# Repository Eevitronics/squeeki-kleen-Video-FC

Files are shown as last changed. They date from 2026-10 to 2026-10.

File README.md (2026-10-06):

# squeeki-kleen-Video-FC

> **Note:** This is a modified version of [squeeki-kleen Video FC](https://github.com/Gumball2415/squeeki-kleen-Video-FC) by Persune, adapted by Eevitronics. The MMCX connector has been replaced with solder-wire pads. See [CHANGES.md](CHANGES.md) for the full list of modifications, which are licensed under the TAPR Open Hardware License.

An open source hardware external composite video bypass preamplifier modboard
for the Famicom/NES

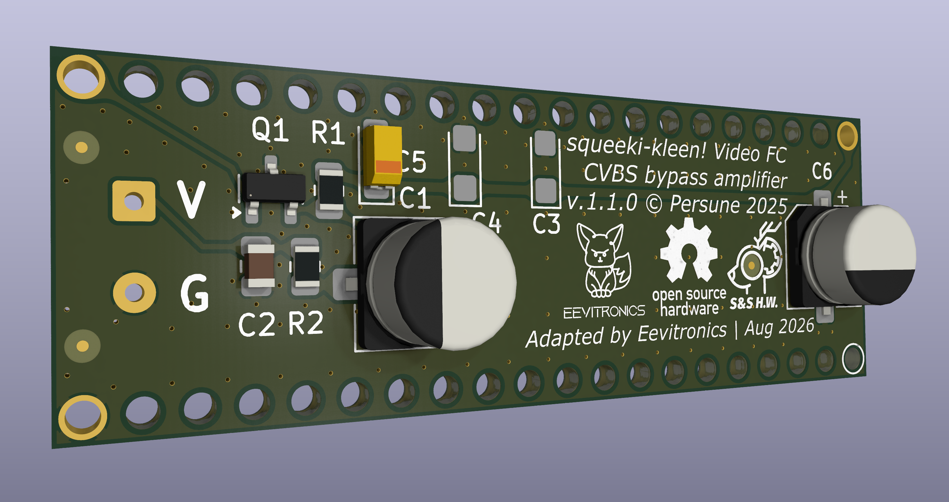
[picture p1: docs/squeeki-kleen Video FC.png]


## Buy assembled boards

Assembled boards of this Eevitronics version are available from the
[Eevitronics Store](https://www.eevitronics.jp). Full design files, including
Gerbers and BOM, remain freely available in this repository under the TAPR
Open Hardware License.

This version is not affiliated with or supported by Persune. For support with
Eevitronics boards, please contact Eevitronics.

## About

I made a compact daughterboard composite video output based on the
[composite amplifier circuit from the AV Famicom](https://www.nesdev.org/wiki/PPU_pinout#Composite_Video_Output).
This is designed to make AV modding RF-only consoles such as the RF Famicom and the Toploading NES-101 compact and simple.

## How to install

TODO: image demonstrations.

1. If your board does not have tented vias, cover the area underneath the PPU with insulating tape. Be sure to also cover underneath the video/ground wire pads to avoid shorts.
2. To reduce stray inductive connections, isolate pin 21 of the PPU by cutting any traces connecting to it as close to the through-hole pad as much as possible.
3. If needed, add additional bypass capacitors in the empty C3 and C4 footprints.

## PCB specifications

Note that this project is optimized for JLCPCB manufacturing.

- 2 layers
- 50.80 x 17.78 mm
- 0.8 mm thickness
- Any surface finish
- Any soldermask/silkscreen color
- Tented vias
	- alternatively, cover area under board with kapton/insulative tape

## License

This is licensed under the [TAPR Open Hardware Licence](https://tapr.org/the-tapr-open-hardware-license/). Copyright Persune 2025. Modifications by Eevitronics 2026, see [CHANGES.md](CHANGES.md).

## Credits

Special thanks to:
- The NESDev community for advice and help
- lidnariq for advice
- Finny (grievre/arreffem) for inspiration
- j4m13c0 for testing the board (and notifying me of Q1 pinout error!)

## Support

If you enjoy this project or find it helpful, please support me using the links below!

- 
- [Patreon](https://patreon.com/persune)

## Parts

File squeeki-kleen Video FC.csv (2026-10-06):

Id | Designator | Footprint | Quantity | Designation | Supplier and ref
1 | , , , , , , , , , , , , , , , , , , , , , , , , , , , , , , , , , , , , |  | 37
2 | C1 | CP_Elec_6.3x5.4 | 1 | 220uF
3 | C2 | C_0805_2012Metric | 1 | 560pF
4 | C5 | CP_EIA-3216-18_Kemet-A | 1 | 10uF
5 | C6 | CP_Elec_6.3x4.5 | 1 | 100uF
6 | GND | SolderWire-0.25sqmm_1x02_P4.2mm_D0.65mm_OD1.7mm | 1 | Conn_01x02
7 | Q1 | SOT-23 | 1 | MMBT3906
8 | R1 | R_0805_2012Metric | 1 | 300
9 | R2 | R_0805_2012Metric | 1 | 110
10 | REF**, REF**, REF** | Fiducial_0.5mm_Mask1.5mm | 3 | Fiducial_0.5mm_Mask1.5mm

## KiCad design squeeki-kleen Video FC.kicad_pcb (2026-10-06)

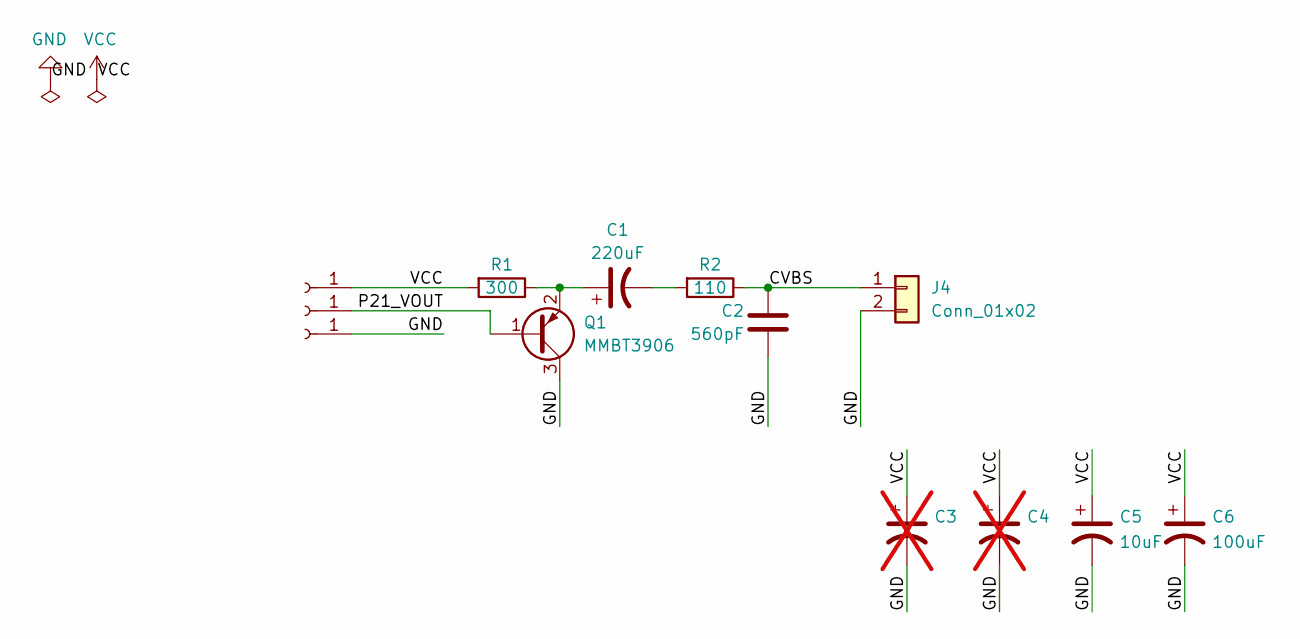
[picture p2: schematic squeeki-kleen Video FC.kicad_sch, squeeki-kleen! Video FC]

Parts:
C1: 220uF; CP_Elec_6.3x5.4; LCSC C72494
C2: 560pF; C_0805_2012Metric; LCSC C527188
C3, C4: CP_EIA-3216-18_Kemet-A; LCSC C1508940; not fitted
C5: 10uF; CP_EIA-3216-18_Kemet-A; LCSC C1508940
C6: 100uF; CP_Elec_6.3x4.5; LCSC C5374788
J1: VCC; THT_Hole
J2: VOUT; THT_Hole
J3: GND; THT_Hole
J4: Conn_01x02; SolderWire-0.25sqmm_1x02_P4.2mm_D0.65mm_OD1.7mm
Q1: MMBT3906; SOT-23; LCSC C2891809
R1: 300; R_0805_2012Metric; LCSC C17617
R2: 110; R_0805_2012Metric; LCSC C229072

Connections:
/CVBS: C2.1, J4.1, R2.1; also elsewhere on the board
/P21_VOUT: J2.1 (Pin_1_1), Q1.1 (B)
GND: C2.2, C3.2, C4.2, C5.2, C6.2, J3.1 (Pin_1_1), J4.2, Q1.3 (C); also elsewhere on the board
unnamed: C1.2, R2.2
unnamed: C1.1, Q1.2 (E), R1.1
VCC: C3.1, C4.1, C5.1, C6.1, J1.1 (Pin_1_1), R1.2

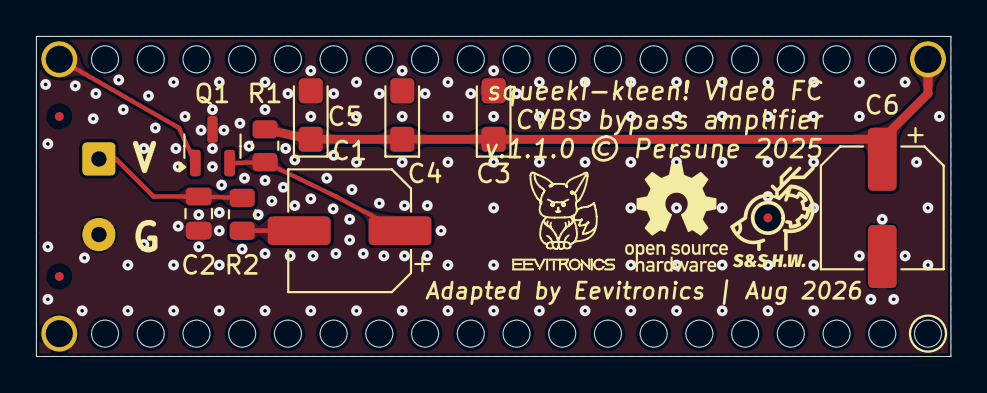
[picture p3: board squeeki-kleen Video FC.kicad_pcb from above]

Board: 2 copper layers, 50.8 x 17.8 mm, 15 parts (0 on the bottom side), 6 nets.

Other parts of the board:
GND: Conn_01x02; SolderWire-0.25sqmm_1x02_P4.2mm_D0.65mm_OD1.7mm
svg2mod: G***; maustech icon fiducial 0-50mm 1-50mm
svg2mod#2: G***; oshw-logo 6x6mm

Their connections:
/CVBS: GND.1; also elsewhere on the board
GND: GND.2; also elsewhere on the board

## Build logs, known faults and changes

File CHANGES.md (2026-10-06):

# Modifications by Eevitronics

This repository is a modified version of
[squeeki-kleen Video FC](https://github.com/Gumball2415/squeeki-kleen-Video-FC)
by Persune (© Persune 2025), based on upstream commit `db85869` (v1.1.0).

**These modifications are licensed under the terms of the TAPR Open Hardware
License v1.0** (see `LICENSE.txt`), the same license as the original design.

The original, unmodified versions of every changed file are kept in this
repository's git history (all commits up to and including `db85869`).

## Changed files

### `squeeki-kleen Video FC.kicad_sch` (schematic)
- J4: replaced the MMCX coaxial connector
  (`Connector_Coaxial:MMCX_Molex_73415-0961_Horizontal_0.8mm-PCB`, `Conn_Coaxial`)
  with a 2-pin solder-wire connection
  (`Connector_Wire:SolderWire-0.25sqmm_1x02_P4.2mm_D0.65mm_OD1.7mm`, `Conn_01x02`)
  for video out and ground.
- C3/C4 (unpopulated): value field changed from `~` to empty.
- Re-saved in KiCad 10.

### `squeeki-kleen Video FC.kicad_pcb` (PCB layout)
- J4 footprint changed from MMCX connector to solder-wire pads, with routing
  updated to suit.
- Added silkscreen labels `V` (video out) and `G` (ground) for the J4 pads.
- Added silkscreen text `Adapted by Eevitronics | Aug 2026`.
- Removed the QR code graphic and the `JLCJLCJLCJLC` order-number placeholder.
- The original "squeeki-kleen! Video FC / v.1.1.0 © Persune 2025" silkscreen
  and OSHW logo are kept unchanged.
- Re-saved in KiCad 10.

### `squeeki-kleen Video FC.kicad_pro` (project settings)
- Updated by KiCad 10 (new default settings), and Gerber plot output directory
  set to `gerber_jlcpcb/`.

### `docs/squeeki-kleen Video FC.png`
- Updated render of the modified board.

## New files
- `gerber_jlcpcb/`: Gerber and drill files for JLCPCB manufacture
  (also bundled as `Archive.zip`).
- `squeeki-kleen Video FC.csv`: bill of materials.
- `bom/ibom.html`: interactive BOM / assembly guide.

## Documentation
- `README.md`: added a note that this is a modified fork, a "Buy assembled
  boards" section, and updated MMCX references in the install steps and PCB
  specifications to match the solder-wire pads.
